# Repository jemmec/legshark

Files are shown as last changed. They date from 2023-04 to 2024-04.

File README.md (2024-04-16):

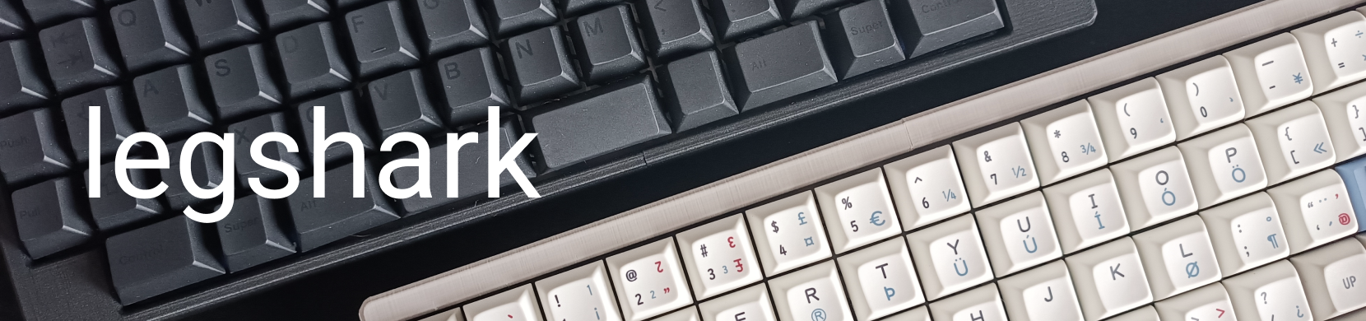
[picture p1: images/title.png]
title


# legshark

An open source 60% (15 by 5) ortholinear keyboard designed with both flexability and familiarity in mind.

- Highly customizable 60% ortho layout
- "Plateless" o-ring mounting
- 3D printable case
- [UDB](https://github.com/Unified-Daughterboard/) Support

### Layout

The PCB supports many different layout options for the bottom row, embracing `1u` keys but also with some left and right `1.5u` modifier options.

The board also supports use of `2u` keys in the usual `TAB`, `LSHIFT`, `DELETE`, and `ENTER` locations to maintain familiarity and speed with these often used modifiers.

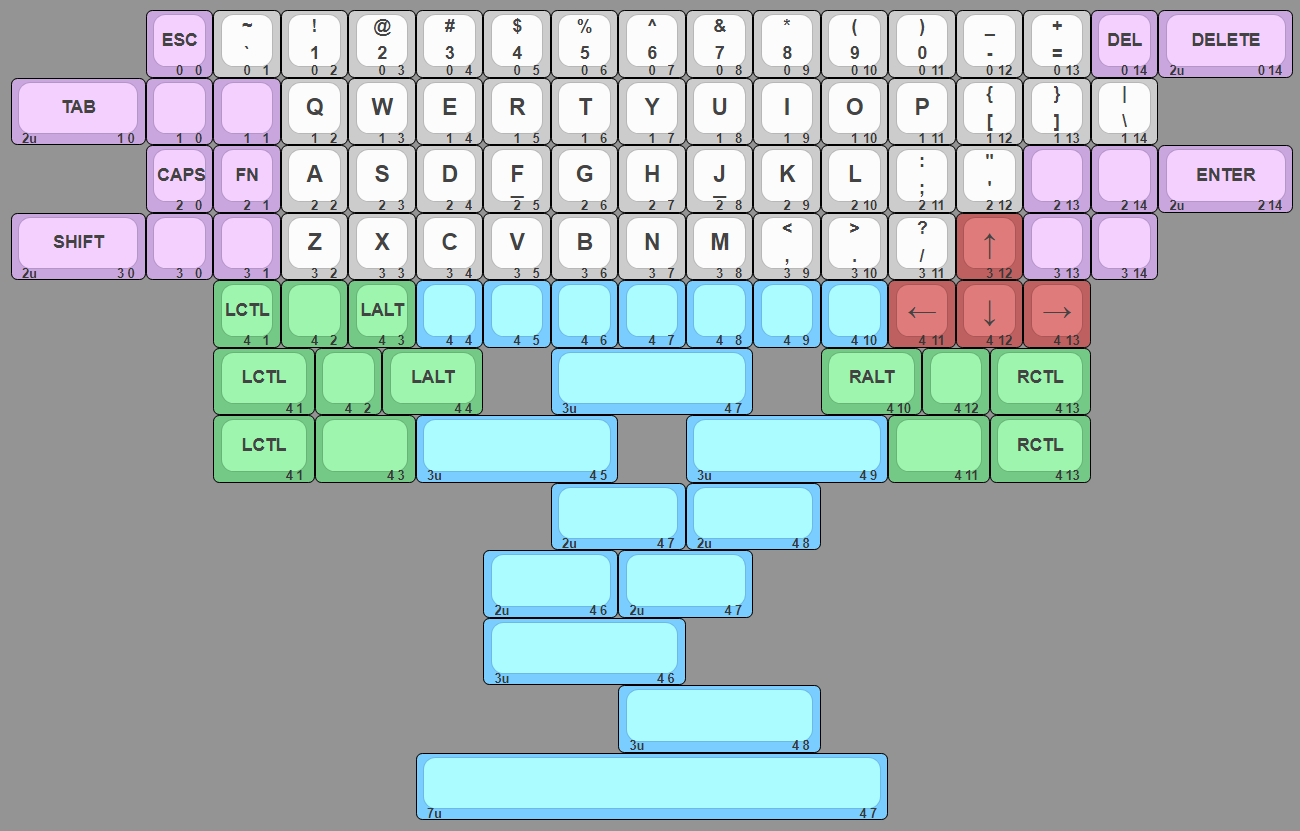
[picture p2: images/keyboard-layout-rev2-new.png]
keyboard-layout Rev2


### PCB

> NOTE: It is recommended to use screw-in stabilizers (yes they work with o-ring) due to clip-ins sometimes slipping between the three holes in the bottom row. I have slightly reduced the clip-in hole size which has mitigated the issue, but made them quite hard to push in.

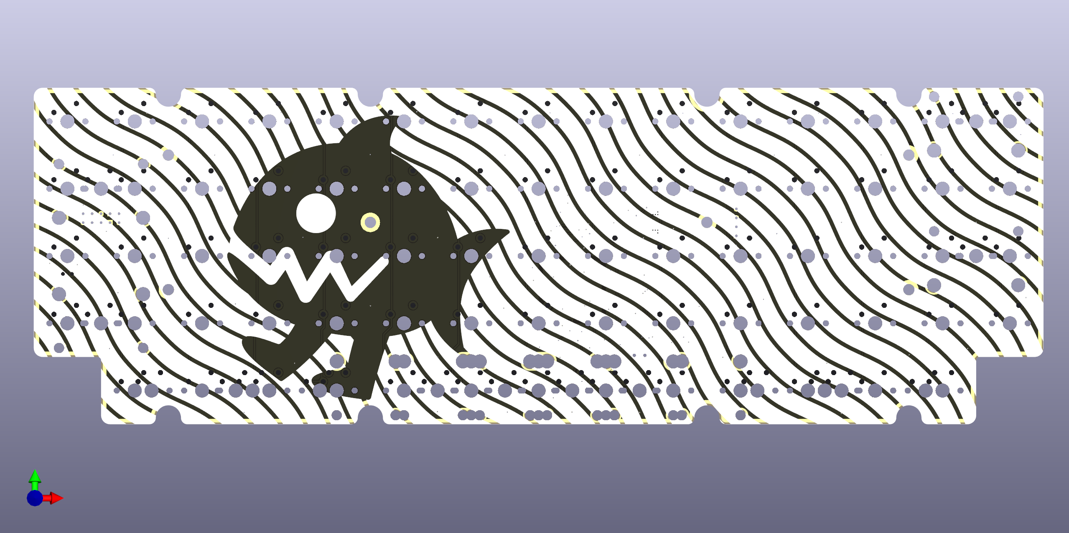
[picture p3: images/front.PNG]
front

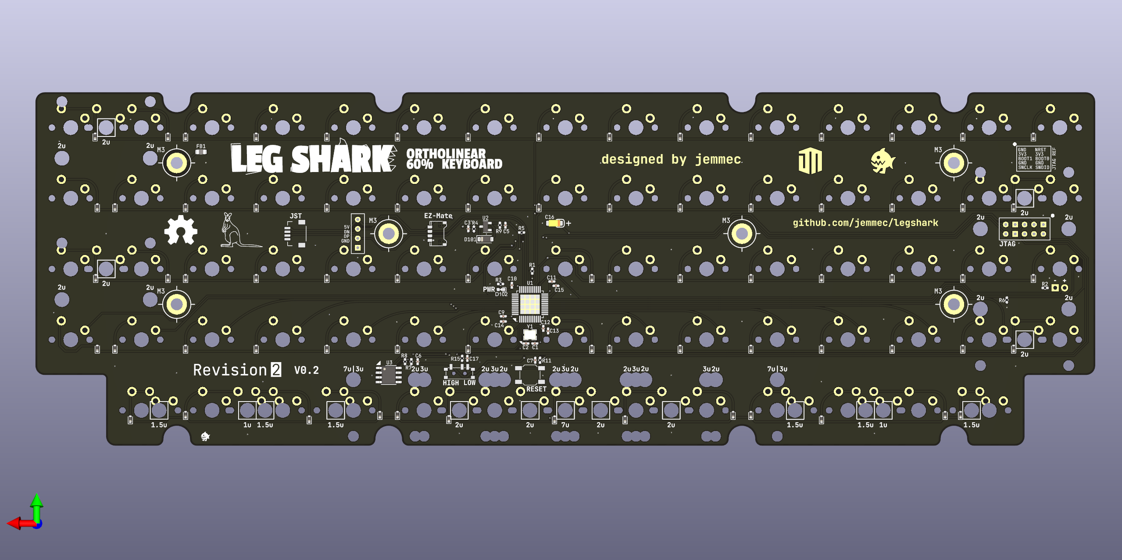
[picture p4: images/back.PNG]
back

>_These images may not be up-to-date._

Supports the [Unified Daughterboard](https://github.com/Unified-Daughterboard/).

### Mounting Styles

Supports a unique "plateless" o-ring mounting style. The PCB also has through-holes for plate mounting should that be preferred.

#### "Plateless" o-ring plate

The "plateless" o-ring mounting style lets you enjoy the unique characteristics and sound of a platless + o-ring board with the added benefit of being able to remove/change the plate after soldering in the switches.

The printable plate files can be found in `./stls`. There are two files, one for `1.5u` spaced switches (pictured) and one for the `1u` spaced switches. Only the left side plate is supplied, you will need to vertically mirror the file in your slicer to print the right side. The optimal printing orientation is upside-down.

A standard 60% o-ring (OD 180-190mm) with a diameter of 2.5-3.5mm will work. 

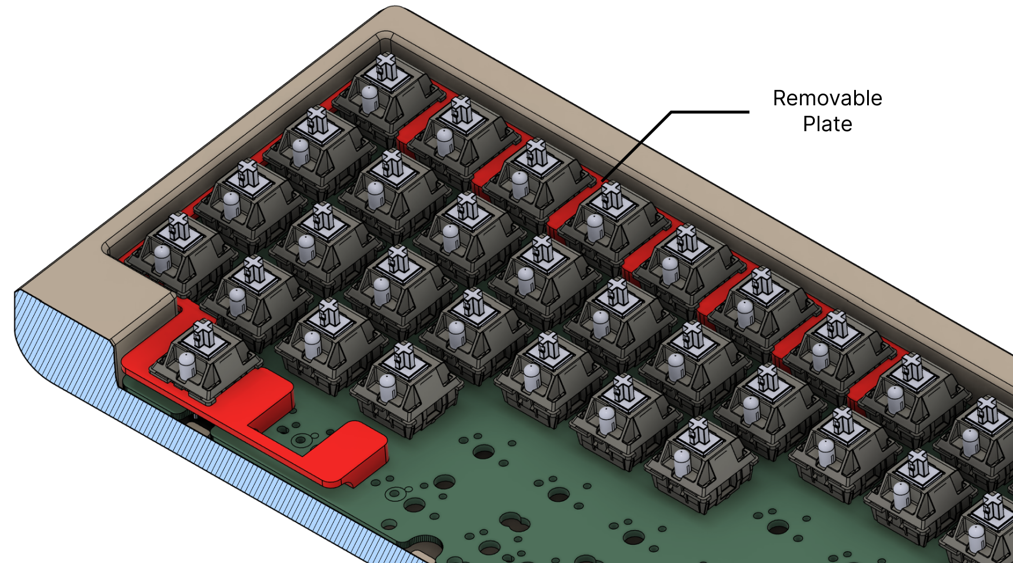
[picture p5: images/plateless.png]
plateless


>NOTE: If you intend to use a layout with the `2u` SHIFT or DELETE keys these plates may need modified in order to fit the stabs.

### Case

A 3D printable case designed around the "plateless" o-ring mounting system. It's a unibody design with a daughterboard cutout and recessed holes for 12mm rubber feet. The daughterboard is screwed into M2 threaded inserts.

Files for printing the case can be found in `./stls`. The print has been split into two parts, since it is too large for standard-sized printer volumes. The two halves are designed to be glued together using key and slot guides for alignment and added strength. The optimal printing orientation is vertically with the case-sides facing down.

>NOTE: I recommend using superglue to bond the two halves together.
>1) Glue all three keys into the slots of one of the halves. 
>2) Add glue along the mating surface and in the slots of the other half. 
>3) Carefully slide the two halves together using the keys and slots a guide. 
>4) Clamp the halves together and let the glue dry for 10-20 minutes.

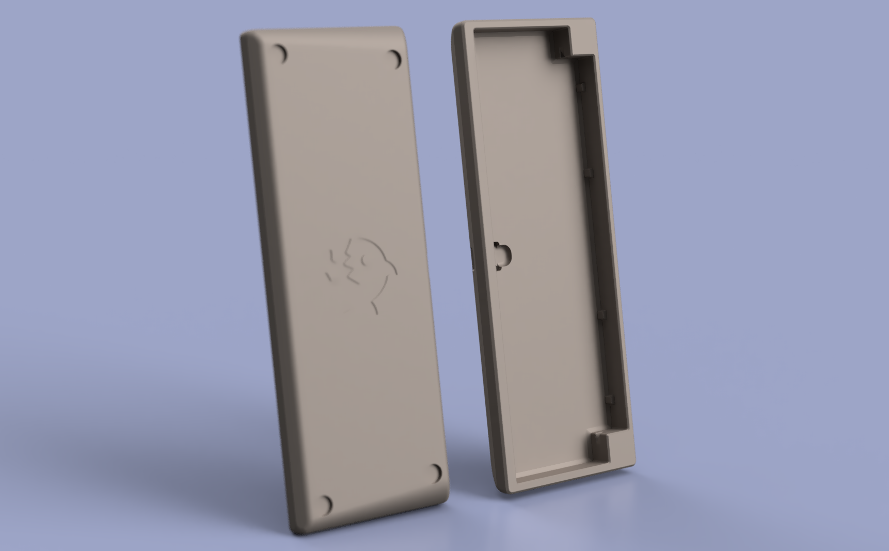
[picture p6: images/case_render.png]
case


### QMK

There is only one keymap avaliable for the keyboard currently. This keyboard has not been merged into the qmk repo yet. The firmware will need to be compiled and uploaded locally using [QMK](https://qmk.fm/). 

Copy `./qmk/keyboards` into your `/qmk_firmware` folder then run the following command to compile the firmware:
```
qmk compile -kb legshark/rev2 -km default
```

>NOTE: You will need to modify the keymaps to support different layouts!

### Keyboard Layout Editor:

```
[{x:2,c:"#c9a6de",t:"#383838",st:"KS-3-Tea",a:3,f:4},"ESC\n\n\n\n\n0\n\n\n\n\n\n0",{c:"#cccccc",a:1},"~\n`\n\n\n\n1\n\n\n\n\n\n0","!\n1\n\n\n\n2\n\n\n\n\n\n0","@\n2\n\n\n\n3\n\n\n\n\n\n0","#\n3\n\n\n\n4\n\n\n\n\n\n0","$\n4\n\n\n\n5\n\n\n\n\n\n0","%\n5\n\n\n\n6\n\n\n\n\n\n0","^\n6\n\n\n\n7\n\n\n\n\n\n0","&\n7\n\n\n\n8\n\n\n\n\n\n0","*\n8\n\n\n\n9\n\n\n\n\n\n0","(\n9\n\n\n\n10\n\n\n\n\n\n0",")\n0\n\n\n\n11\n\n\n\n\n\n0","_\n-\n\n\n\n12\n\n\n\n\n\n0","+\n=\n\n\n\n13\n\n\n\n\n\n0",{c:"#c9a6de",a:3},"DEL\n\n\n\n\n14\n\n\n\n\n\n0",{w:2},"DELETE\n\n\n\n2u\n0 14"],
[{w:2},"TAB\n\n\n\n2u\n1 0","\n\n\n\n\n0\n\n\n\n\n\n1","\n\n\n\n\n1\n\n\n\n\n\n1",{c:"#cccccc",f:6},"Q\n\n\n\n\n2\n\n\n\n\n\n1","W\n\n\n\n\n3\n\n\n\n\n\n1","E\n\n\n\n\n4\n\n\n\n\n\n1","R\n\n\n\n\n5\n\n\n\n\n\n1","T\n\n\n\n\n6\n\n\n\n\n\n1","Y\n\n\n\n\n7\n\n\n\n\n\n1","U\n\n\n\n\n8\n\n\n\n\n\n1","I\n\n\n\n\n9\n\n\n\n\n\n1","O\n\n\n\n\n10\n\n\n\n\n\n1","P\n\n\n\n\n11\n\n\n\n\n\n1",{a:1,f:4},"{\n[\n\n\n\n12\n\n\n\n\n\n1","}\n]\n\n\n\n13\n\n\n\n\n\n1","|\n\\\n\n\n\n14\n\n\n\n\n\n1"],
[{x:2,c:"#c9a6de",a:3},"CAPS\n\n\n\n\n0\n\n\n\n\n\n2","FN\n\n\n\n\n1\n\n\n\n\n\n2",{c:"#cccccc",f:6},"A\n\n\n\n\n2\n\n\n\n\n\n2","S\n\n\n\n\n3\n\n\n\n\n\n2","D\n\n\n\n\n4\n\n\n\n\n\n2",{a:1},"\n_\n\n\n\n5\nF\n\n\n\n\n2",{a:3},"G\n\n\n\n\n6\n\n\n\n\n\n2","H\n\n\n\n\n7\n\n\n\n\n\n2",{a:1},"\n_\n\n\n\n8\nJ\n\n\n\n\n2",{a:3},"K\n\n\n\n\n9\n\n\n\n\n\n2","L\n\n\n\n\n10\n\n\n\n\n\n2",{a:1,f:4},":\n;\n\n\n\n11\n\n\n\n\n\n2","\"\n'\n\n\n\n12\n\n\n\n\n\n2",{c:"#c9a6de",a:3},"\n\n\n\n\n13\n\n\n\n\n\n2","\n\n\n\n\n14\n\n\n\n\n\n2",{w:2},"ENTER\n\n\n\n2u\n2 14"],
[{w:2},"SHIFT\n\n\n\n2u\n3 0","\n\n\n\n\n0\n\n\n\n\n\n3","\n\n\n\n\n1\n\n\n\n\n\n3",{c:"#cccccc",f:6},"Z\n\n\n\n\n2\n\n\n\n\n\n3","X\n\n\n\n\n3\n\n\n\n\n\n3","C\n\n\n\n\n4\n\n\n\n\n\n3","V\n\n\n\n\n5\n\n\n\n\n\n3","B\n\n\n\n\n6\n\n\n\n\n\n3","N\n\n\n\n\n7\n\n\n\n\n\n3","M\n\n\n\n\n8\n\n\n\n\n\n3",{a:1,f:4},"<\n,\n\n\n\n9\n\n\n\n\n\n3",">\n.\n\n\n\n10\n\n\n\n\n\n3","?\n/\n\n\n\n11\n\n\n\n\n\n3",{c:"#bf6060",a:3,f:9},"↑\n\n\n\n\n12\n\n\n\n\n\n3",{c:"#c9a6de",f:4},"\n\n\n\n\n13\n\n\n\n\n\n3","\n\n\n\n\n14\n\n\n\n\n\n3"],
[{x:3,c:"#73c985"},"LCTL\n\n\n\n\n1\n\n\n\n\n\n4","\n\n\n\n\n2\n\n\n\n\n\n4","LALT\n\n\n\n\n3\n\n\n\n\n\n4",{c:"#7acdff",sm:"alps"},"\n\n\n\n\n4\n\n\n\n\n\n4","\n\n\n\n\n5\n\n\n\n\n\n4","\n\n\n\n\n6\n\n\n\n\n\n4","\n\n\n\n\n7\n\n\n\n\n\n4","\n\n\n\n\n8\n\n\n\n\n\n4","\n\n\n\n\n9\n\n\n\n\n\n4","\n\n\n\n\n10\n\n\n\n\n\n4",{c:"#bf6060",f:9},"←\n\n\n\n\n11\n\n\n\n\n\n4","↓\n\n\n\n\n12\n\n\n\n\n\n4","→\n\n\n\n\n13\n\n\n\n\n\n4"],
[{x:3,c:"#73c985",f:4,w:1.5},"LCTL\n\n\n\n\n4 1","\n\n\n\n\n2\n\n\n\n\n\n4",{w:1.5},"LALT\n\n\n\n\n4 4",{x:1,c:"#7acdff",w:3},"\n\n\n\n3u\n4 7",{x:1,c:"#73c985",w:1.5},"RALT\n\n\n\n\n4 10","\n\n\n\n\n4 12",{w:1.5},"RCTL\n\n\n\n\n4 13"],
[{x:3,w:1.5},"LCTL\n\n\n\n\n4 1",{w:1.5},"\n\n\n\n\n4 3",{c:"#7acdff",w:3},"\n\n\n\n3u\n4 5",{x:1,w:3},"\n\n\n\n3u\n4 9",{c:"#73c985",w:1.5},"\n\n\n\n\n4 11",{w:1.5},"RCTL\n\n\n\n\n4 13"],
[{x:8,c:"#7acdff",w:2},"\n\n\n\n2u\n4 7",{w:2},"\n\n\n\n2u\n4 8"],
[{x:7,w:2},"\n\n\n\n2u\n4 6",{w:2},"\n\n\n\n2u\n4 7"],
[{x:7,w:3},"\n\n\n\n3u\n4 6"],
[{x:9,w:3},"\n\n\n\n3u\n4 8"],
[{x:6,w:7},"\n\n\n\n7u\n4 7"]
```
# Liability

This open source hardware is provided as is and can not be held accountable for any damages and/or liabilities caused as a result of whatever you intend to use it for.

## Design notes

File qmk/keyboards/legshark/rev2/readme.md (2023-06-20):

# legshark65

legshark65

*A short description of the keyboard/project*

* Keyboard Maintainer: [jemmec](https://github.com/jemmec)
* Hardware Supported: *The PCBs, controllers supported*
* Hardware Availability: *Links to where you can find this hardware*

Make example for this keyboard (after setting up your build environment):

    make legshark65:default

Flashing example for this keyboard:

    make legshark65:default:flash

See the [build environment setup](https://docs.qmk.fm/#/getting_started_build_tools) and the [make instructions](https://docs.qmk.fm/#/getting_started_make_guide) for more information. Brand new to QMK? Start with our [Complete Newbs Guide](https://docs.qmk.fm/#/newbs).

## Bootloader

Enter the bootloader in 3 ways:

* **Bootmagic reset**: Hold down the key at (0,0) in the matrix (usually the top left key or Escape) and plug in the keyboard
* **Physical reset button**: Briefly press the button on the back of the PCB - some may have pads you must short instead
* **Keycode in layout**: Press the key mapped to `QK_BOOT` if it is available

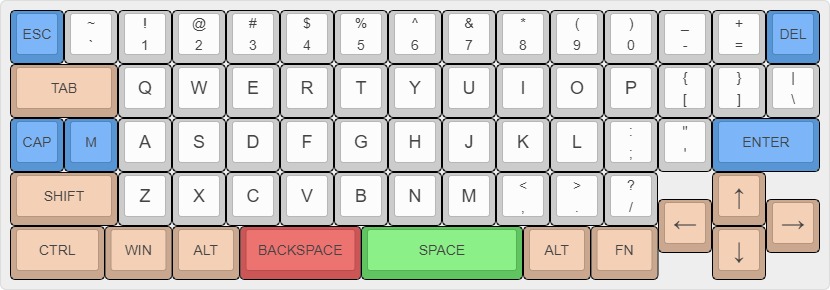
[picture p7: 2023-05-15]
images/keyboard-layout-v2.1.jpg

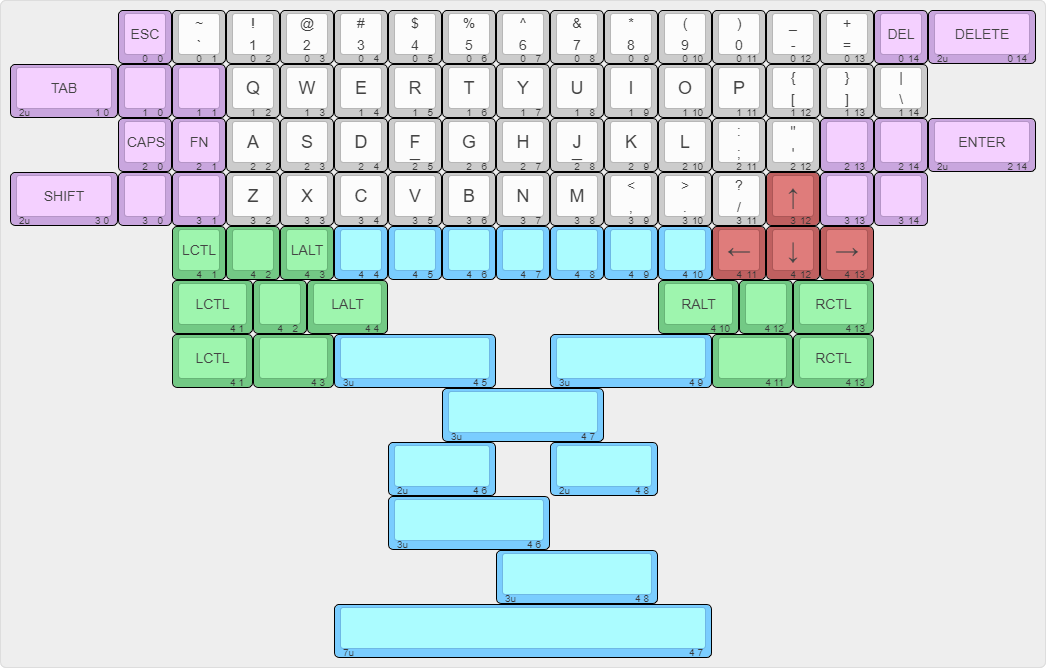
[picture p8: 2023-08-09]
images/keyboard-layout_rev2.png

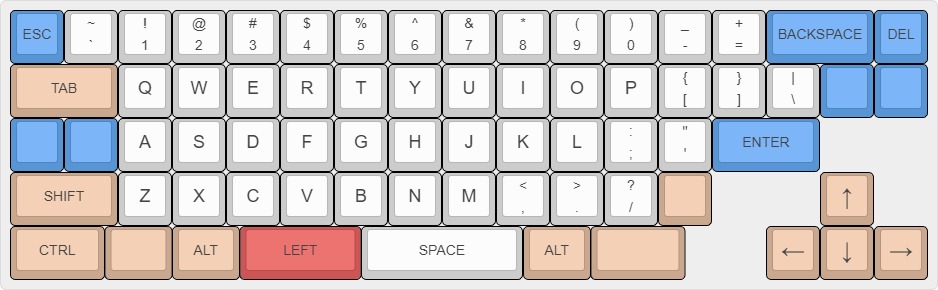
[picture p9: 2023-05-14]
images/keyboard-layout-v2.jpg

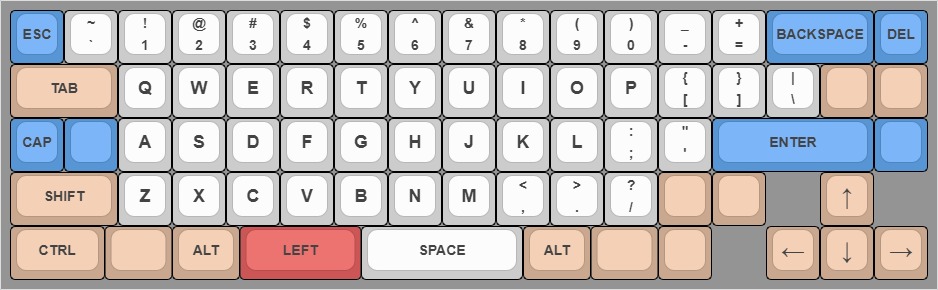
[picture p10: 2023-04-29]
images/keyboard-layout-v1.jpg

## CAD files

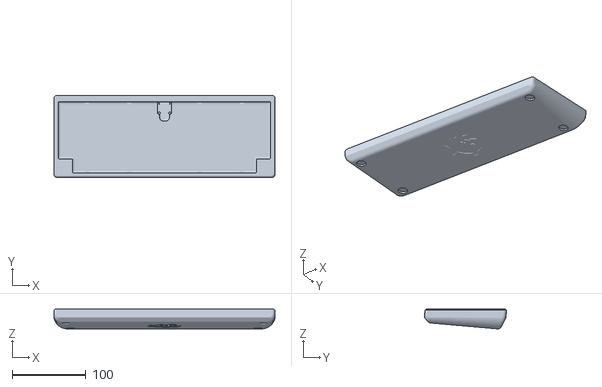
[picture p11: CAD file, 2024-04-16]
stls/case-body-whole.stl
298.8 x 111.1 x 26.7

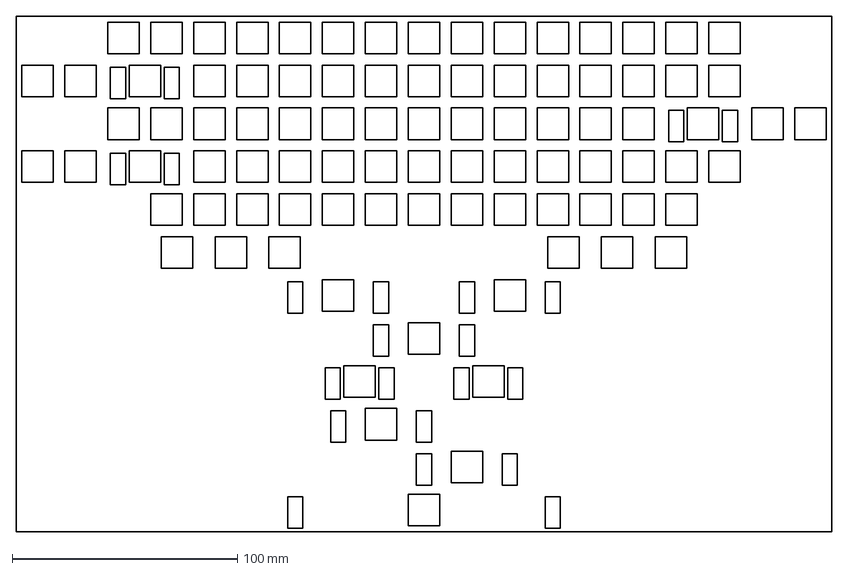
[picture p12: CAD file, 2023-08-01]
plate/Rev2/plate-2023-08-01T08_43_06.286Z.dxf
361.9 x 228.6 mm

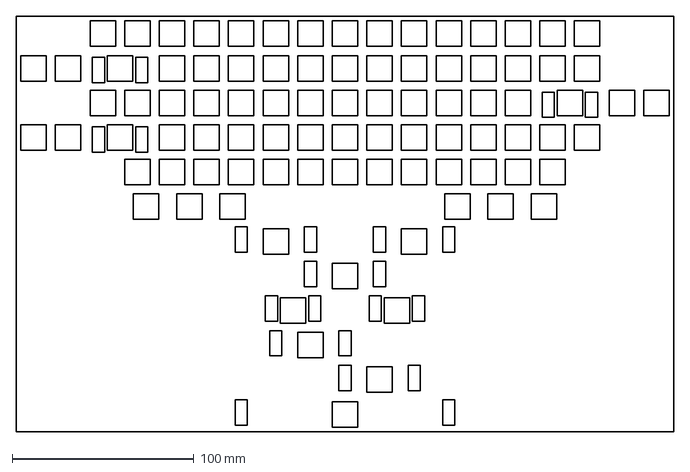
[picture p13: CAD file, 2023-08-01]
plates/rev2/legshark65_rev2_plate.dxf
361.9 x 228.6 mm

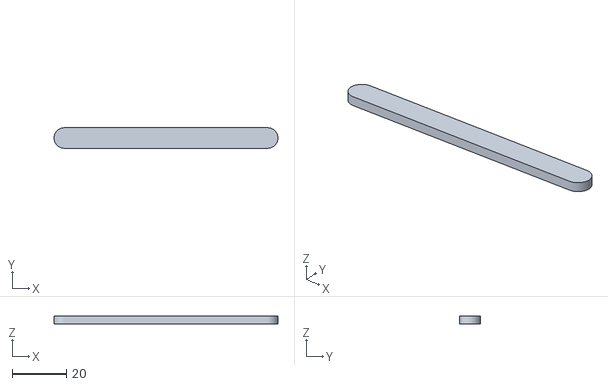
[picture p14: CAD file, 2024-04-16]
stls/case-key-small.stl
82.6 x 7.60 x 2.80

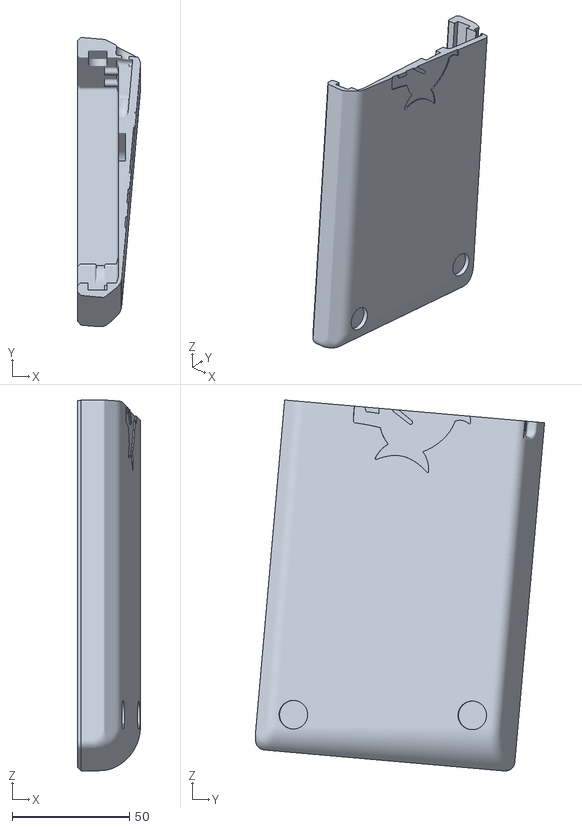
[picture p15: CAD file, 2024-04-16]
stls/case-body-left.stl
26.7 x 123.1 x 158.0

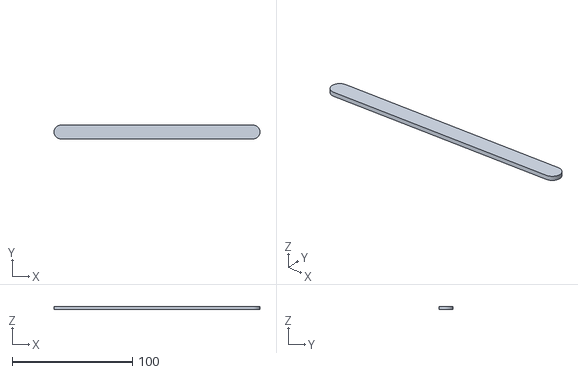
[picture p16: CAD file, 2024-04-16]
stls/case-key-large.stl
171.6 x 11.6 x 2.80

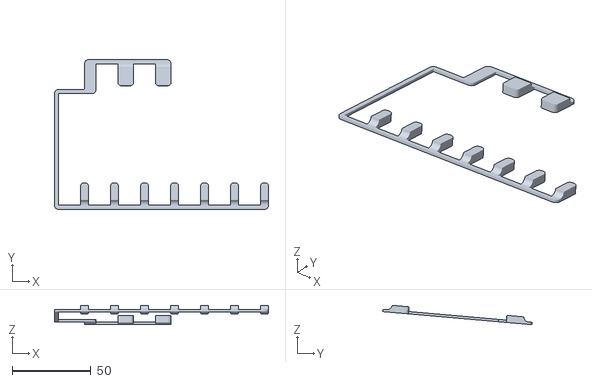
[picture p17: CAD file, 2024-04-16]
stls/plate-1.5u-left.stl
135.9 x 95.0 x 12.3

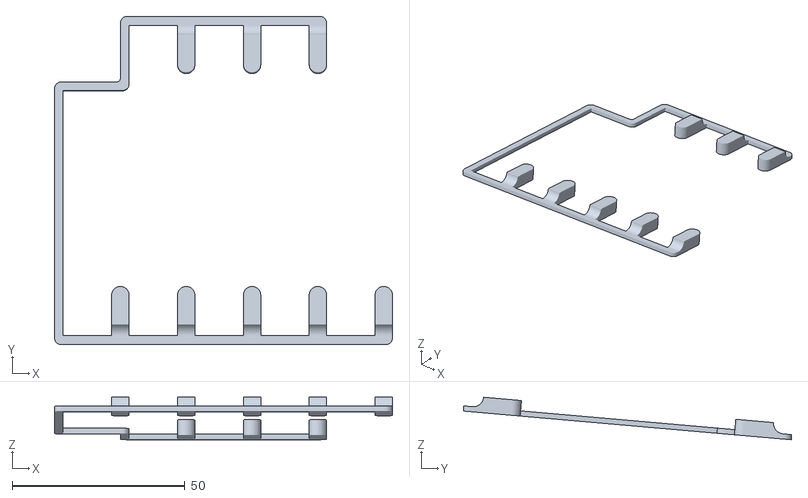
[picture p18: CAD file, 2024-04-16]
stls/plate-1u-left.stl
97.8 x 95.0 x 12.3

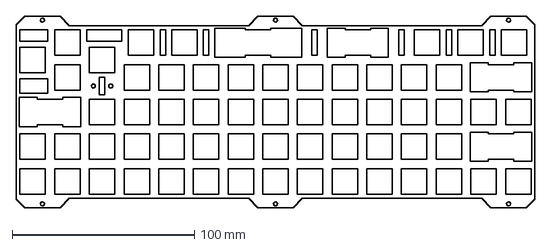
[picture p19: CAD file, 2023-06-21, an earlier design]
plates/rev1/legshark65_plate_0.50tol.dxf
285.0 x 105.0 mm

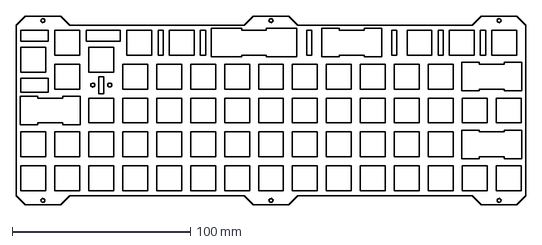
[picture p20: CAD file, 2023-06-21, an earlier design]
plates/rev1/legshark65_plate_0.15tol.dxf
285.7 x 105.7 mm

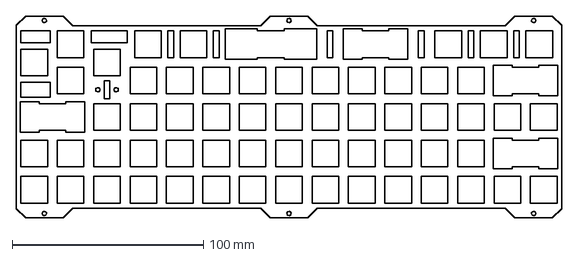
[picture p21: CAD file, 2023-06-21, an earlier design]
plates/rev1/legshark65_plate_0.25tol.dxf
285.5 x 105.5 mm

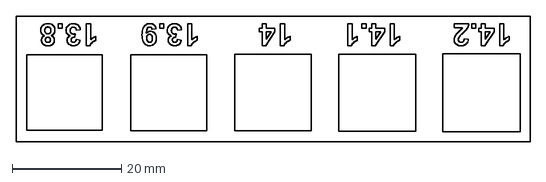
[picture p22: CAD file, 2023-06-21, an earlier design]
plates/rev1/legshark65_switch_tolerance_test.dxf
94.0 x 23.0 mm

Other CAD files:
stls/case-body-right.stl

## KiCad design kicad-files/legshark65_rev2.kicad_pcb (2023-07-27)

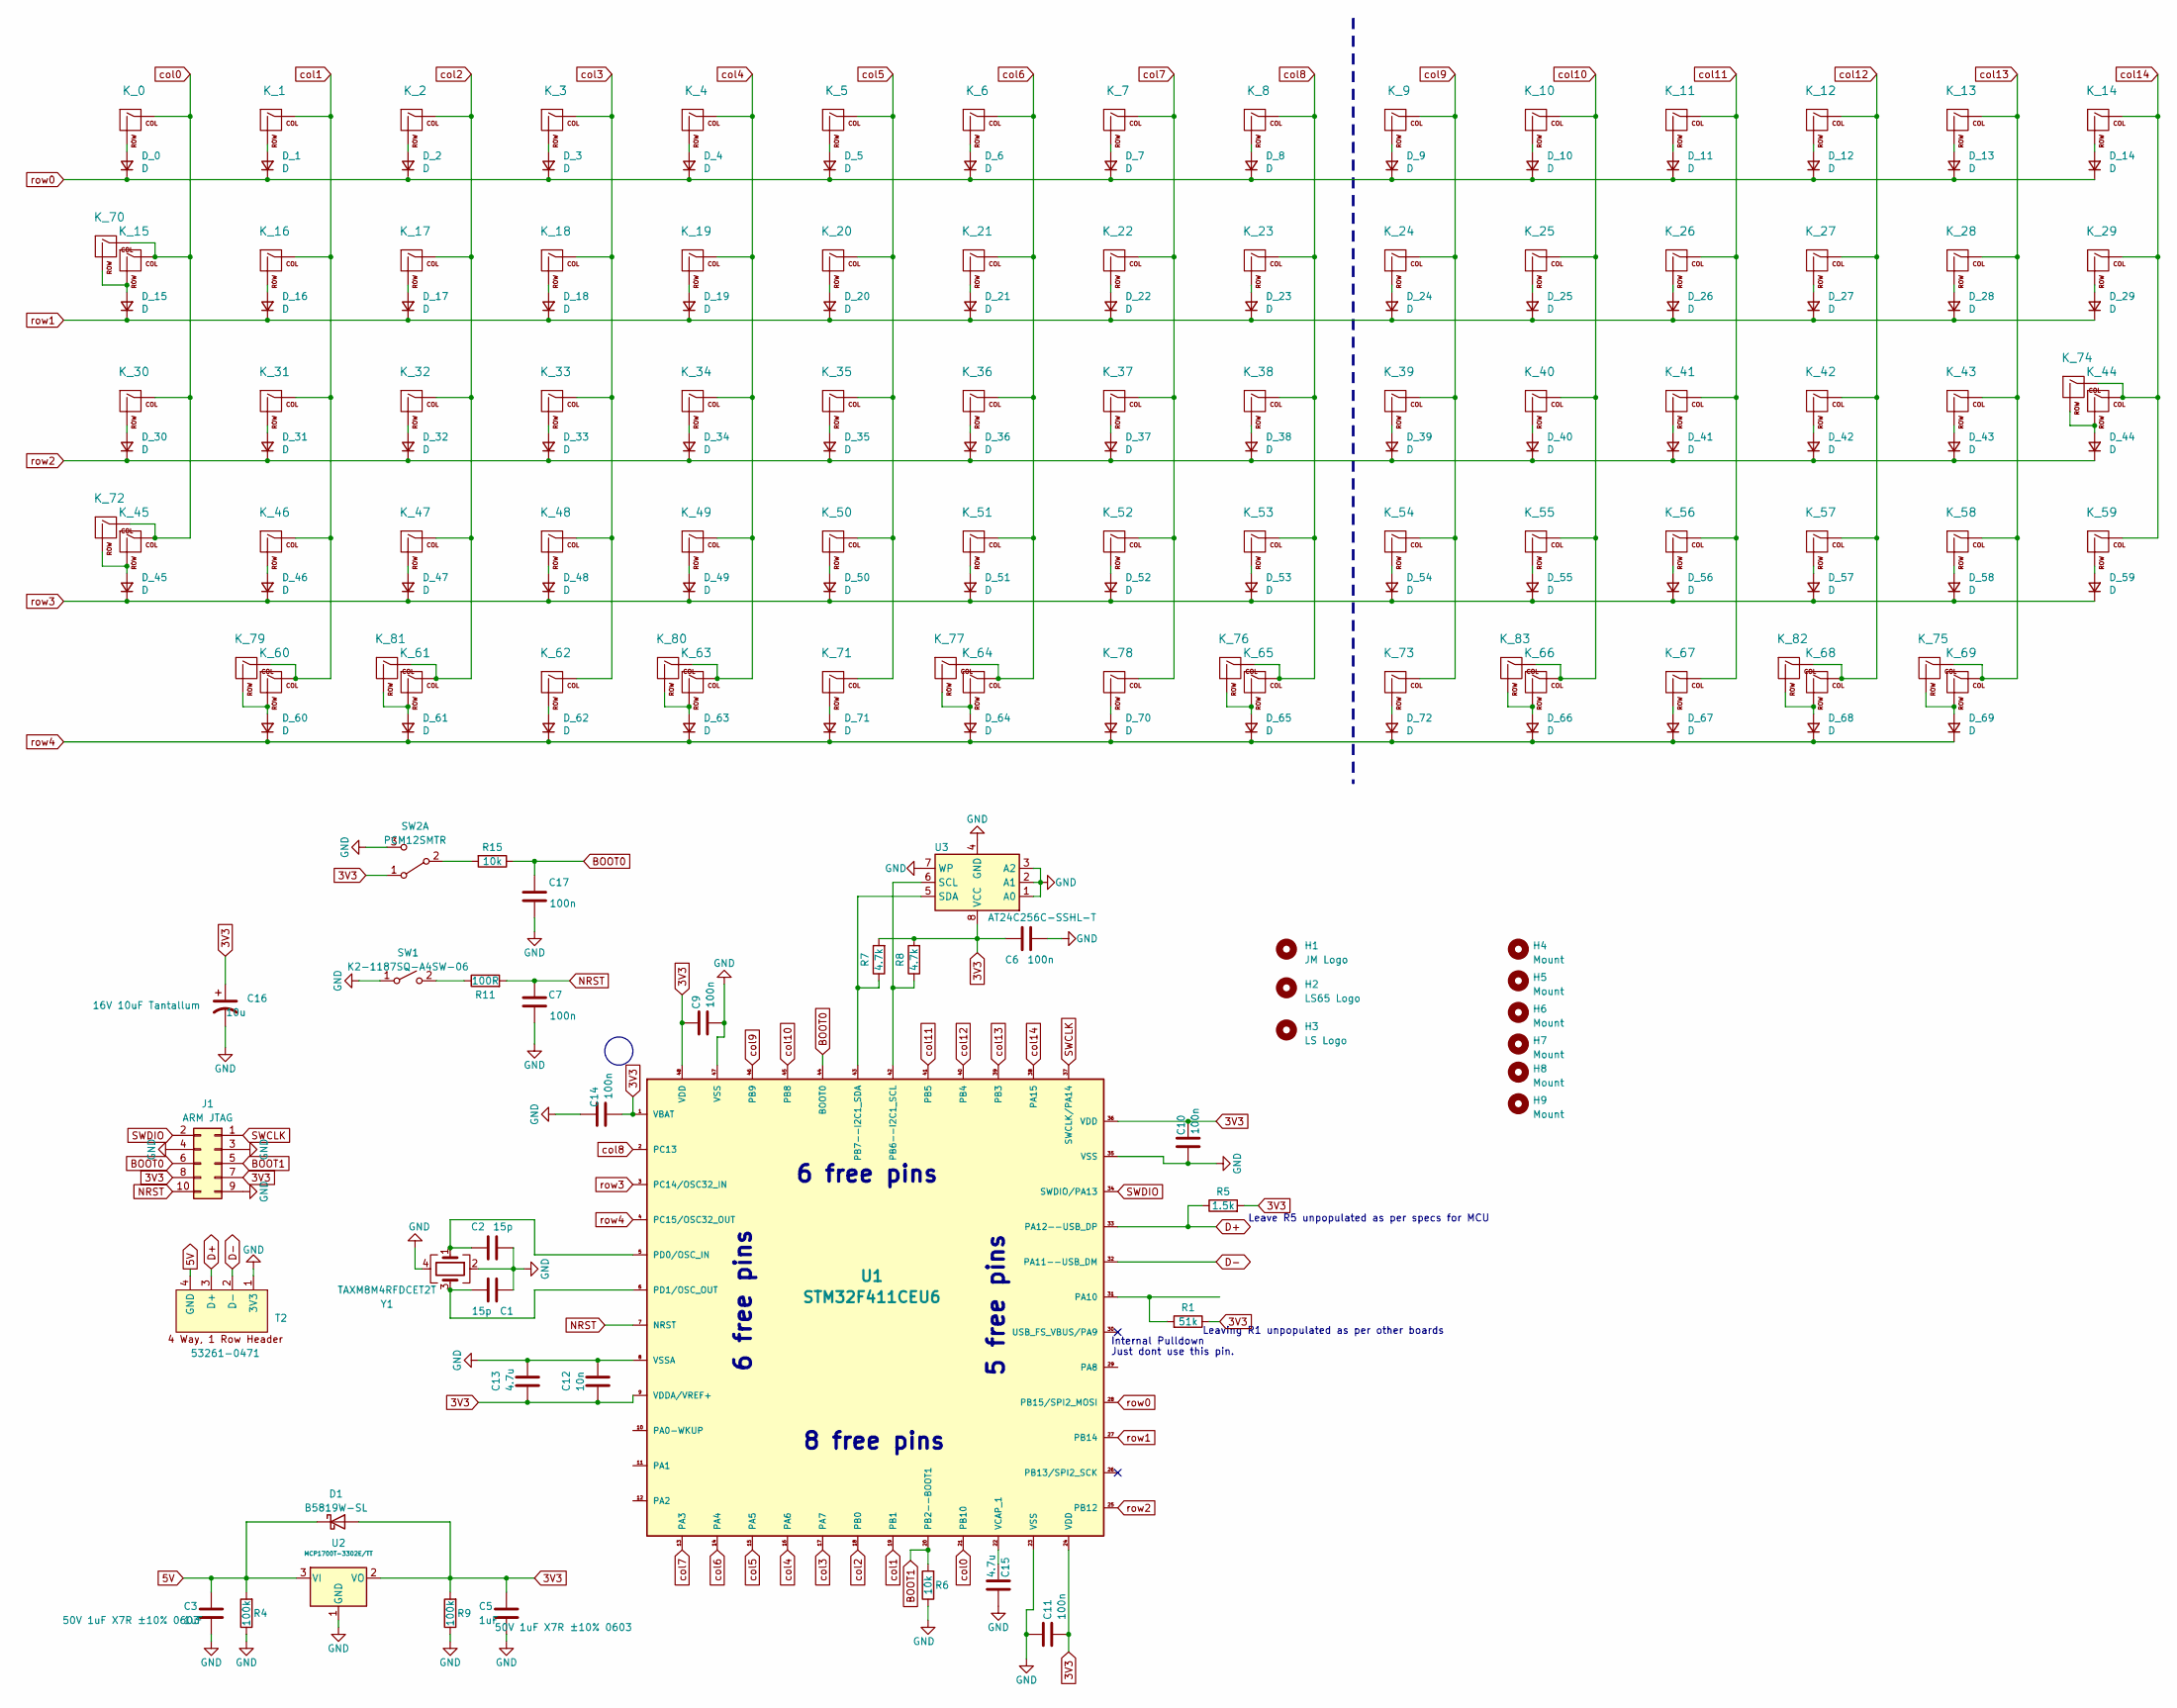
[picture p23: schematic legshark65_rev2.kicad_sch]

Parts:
C1, C2: 15p; C_0402_1005Metric_Pad0.74x0.62mm_HandSolder; Manufacturer Part Number CC0603JRNPO9BN150; LCSC Part C107037
C3, C5: 1uF; C_0402_1005Metric_Pad0.74x0.62mm_HandSolder; Manufacturer Part Number 0603B105K500NT
C6, C7, C9, C10, C11, C14, C17: 100n; C_0402_1005Metric_Pad0.74x0.62mm_HandSolder; Manufacturer Part Number CL10B104KB8NNNC; LCSC Part C1591
C12: 10n; C_0402_1005Metric_Pad0.74x0.62mm_HandSolder; Manufacturer Part Number CL10B103KB8NNNC; LCSC Part C1589
C13, C15: 4.7u; C_0402_1005Metric_Pad0.74x0.62mm_HandSolder; Manufacturer Part Number 0603X475M100NT; LCSC Part C108342
C16: 10u; CP_EIA-3216-10_Kemet-I_Pad1.58x1.35mm_HandSolder; Manufacturer Part Number TAJA106K016RNJ; LCSC Part C7171
D1: B5819W-SL; D_SOD-123
D_0, D_1, D_2, D_3, D_4, D_5, D_6, D_7, D_8, D_9, D_10, D_11, D_12, D_13, D_14, D_15, D_16, D_17, D_18, D_19, D_20, D_21, D_22, D_23, D_24, D_25, D_26, D_27, D_28, D_29, D_30, D_31, D_32, D_33, D_34, D_35, D_36, D_37, D_38, D_39, D_40, D_41, D_42, D_43, D_44, D_45, D_46, D_47, D_48, D_49, D_50, D_51, D_52, D_53, D_54, D_55, D_56, D_57, D_58, D_59, D_60, D_61, D_62, D_63, D_64, D_65, D_66, D_67, D_68, D_69, D_70, D_71, D_72: D; D_SOD-523
H1: JM Logo; jm_logo
H2: LS65 Logo; ls65_logo
H3: LS Logo; Legshark_Mask
H4, H5, H6, H7, H8, H9: Mount; MountingHole_3.2mm_M3_ISO14580
J1: ARM JTAG; PinHeader_2x5_P2.54mm_Vertical
K_0, K_1, K_2, K_3, K_4, K_5, K_6, K_7, K_8, K_9, K_10, K_11, K_12, K_13, K_14, K_15, K_16, K_17, K_18, K_19, K_20, K_21, K_22, K_23, K_24, K_25, K_26, K_27, K_28, K_29, K_30, K_31, K_32, K_33, K_34, K_35, K_36, K_37, K_38, K_39, K_40, K_41, K_42, K_43, K_44, K_45, K_46, K_47, K_48, K_49, K_50, K_51, K_52, K_53, K_54, K_55, K_56, K_57, K_58, K_59, K_60, K_61, K_62, K_63, K_66, K_67, K_68, K_69, K_71, K_73, K_81, K_82: KEYSW; MXOnly-1U-NoLED
K_64, K_76: KEYSW; MXOnly-2U-ReversedStabilizers-NoLED
K_65, K_77: KEYSW; MXOnly-3U-ReversedStabilizers-NoLED
K_70, K_72, K_74: KEYSW; MXOnly-2U-NoLED
K_75, K_79, K_80, K_83: KEYSW; MXOnly-1.5U-NoLED
K_78: KEYSW; Legshark_MXOnly-7U-3U-ReversedStabilizers-NoLED
R1: 51k; R_0402_1005Metric_Pad0.72x0.64mm_HandSolder
R4, R9: 100k; R_0402_1005Metric_Pad0.72x0.64mm_HandSolder
R5: 1.5k; R_0402_1005Metric_Pad0.72x0.64mm_HandSolder
R6, R15: 10k; R_0402_1005Metric_Pad0.72x0.64mm_HandSolder; Manufacturer Part Number 0603WAF1002T5E; LCSC Part C25804
R7, R8: 4.7k; R_0402_1005Metric_Pad0.72x0.64mm_HandSolder; Manufacturer Part Number 0603WAF4701T5E; LCSC Part C23162
R11: 100R; R_0402_1005Metric_Pad0.72x0.64mm_HandSolder; Manufacturer Part Number 0603WAF1000T5E; LCSC Part C22775
SW1: K2-1187SQ-A4SW-06; Manufacturer Part Number K2-1187SQ-A4SW-06; LCSC Part C92584
SW2: PCM12SMTR; Surface Mount Slide Switch SPDT; Manufacturer Part Number PCM12SMTR; LCSC Part C221841
T2: 53261-0471; Molex, PicoBlade, 53261, 4 Way, 1 Row, Right Angle PCB Head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
U1: STM32F411CEU6; STM_UFQFPN-48_LQFP-48-1EP_7x7mm_P0.5mm_HandSoldering; Manufacturer Part Number STM32F411; LCSC Part C60420
U2: MCP1700T-3302E/TT; SOT-23; Manufacturer Part Number MCP1700T-3302E/TT
U3: AT24C256C-SSHL-T; SOIC-8; Manufacturer Part Number AT24C256C-SSHL-T; LCSC Part C6482
Y1: TAXM8M4RFDCET2T; Crystal_SMD_3225-4Pin_3.2x2.5mm; Manufacturer Part Number TAXM8M4RFDCET2T; LCSC Part C403948

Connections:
3V3: C5.1, C6.1, C9.2, C10.2, C11.2, C12.2, C13.2, C14.1, C16.1, D1.2 (A), J1.7, J1.8, R1.1, R5.2, R7.2, R8.2, R9.2, SW2.1 (A), U1.1 (VBAT), U1.9 (VDDA/VREF+), U1.24 (VDD), U1.36 (VDD), U1.48 (VDD), U2.2 (VO), U3.8 (VCC)
5V: C3.1, D1.1 (K), R4.2, T2.4 (GND), U2.3 (VI)
BOOT0: C17.2, J1.6, R15.1, U1.44 (BOOT0)
BOOT1: J1.5, R6.2, U1.20 (PB2--BOOT1)
D+: R5.1, T2.3 (D+), U1.33 (PA12--USB_DP)
D-: T2.2 (D-), U1.32 (PA11--USB_DM)
GND: C1.1, C2.2, C3.2, C5.2, C6.2, C7.1, C9.1, C10.1, C11.1, C12.1, C13.1, C14.2, C15.2, C16.2, C17.1, J1.3, J1.4, J1.9, R4.1, R6.1, R9.1, SW1.1 (A), SW2.3 (C), T2.1 (3V3), U1.8 (VSSA), U1.23 (VSS), U1.35 (VSS), U1.47 (VSS), U2.1 (GND), U3.1 (A0), U3.2 (A1), U3.3 (A2), U3.4 (GND), U3.7 (WP), Y1.2, Y1.4
NRST: C7.2, J1.10, R11.2, U1.7 (NRST)
unnamed: D_0.2 (A), K_0.2 (ROW)
unnamed: D_1.2 (A), K_1.2 (ROW)
unnamed: D_2.2 (A), K_2.2 (ROW)
unnamed: D_3.2 (A), K_3.2 (ROW)
unnamed: D_4.2 (A), K_4.2 (ROW)
unnamed: D_5.2 (A), K_5.2 (ROW)
unnamed: D_6.2 (A), K_6.2 (ROW)
unnamed: D_7.2 (A), K_7.2 (ROW)
unnamed: D_8.2 (A), K_8.2 (ROW)
unnamed: D_9.2 (A), K_9.2 (ROW)
unnamed: D_10.2 (A), K_10.2 (ROW)
unnamed: D_11.2 (A), K_11.2 (ROW)
unnamed: D_12.2 (A), K_12.2 (ROW)
unnamed: D_13.2 (A), K_13.2 (ROW)
unnamed: D_14.2 (A), K_14.2 (ROW)
unnamed: D_15.2 (A), K_15.2 (ROW), K_70.2 (ROW)
unnamed: D_16.2 (A), K_16.2 (ROW)
unnamed: D_17.2 (A), K_17.2 (ROW)
unnamed: D_18.2 (A), K_18.2 (ROW)
unnamed: D_19.2 (A), K_19.2 (ROW)
unnamed: D_20.2 (A), K_20.2 (ROW)
unnamed: D_21.2 (A), K_21.2 (ROW)
unnamed: D_22.2 (A), K_22.2 (ROW)
unnamed: D_23.2 (A), K_23.2 (ROW)
unnamed: D_24.2 (A), K_24.2 (ROW)
unnamed: D_25.2 (A), K_25.2 (ROW)
unnamed: D_26.2 (A), K_26.2 (ROW)
unnamed: D_27.2 (A), K_27.2 (ROW)
unnamed: D_28.2 (A), K_28.2 (ROW)
unnamed: D_29.2 (A), K_29.2 (ROW)
unnamed: D_30.2 (A), K_30.2 (ROW)
unnamed: D_31.2 (A), K_31.2 (ROW)
unnamed: D_32.2 (A), K_32.2 (ROW)
unnamed: D_33.2 (A), K_33.2 (ROW)
unnamed: D_34.2 (A), K_34.2 (ROW)
unnamed: D_35.2 (A), K_35.2 (ROW)
unnamed: D_36.2 (A), K_36.2 (ROW)
unnamed: D_37.2 (A), K_37.2 (ROW)
unnamed: D_38.2 (A), K_38.2 (ROW)
unnamed: D_39.2 (A), K_39.2 (ROW)
unnamed: D_40.2 (A), K_40.2 (ROW)
unnamed: D_41.2 (A), K_41.2 (ROW)
unnamed: D_42.2 (A), K_42.2 (ROW)
unnamed: D_43.2 (A), K_43.2 (ROW)
unnamed: D_44.2 (A), K_44.2 (ROW), K_74.2 (ROW)
unnamed: D_45.2 (A), K_45.2 (ROW), K_72.2 (ROW)
unnamed: D_46.2 (A), K_46.2 (ROW)
unnamed: D_47.2 (A), K_47.2 (ROW)
unnamed: D_48.2 (A), K_48.2 (ROW)
unnamed: D_49.2 (A), K_49.2 (ROW)
unnamed: D_50.2 (A), K_50.2 (ROW)
unnamed: D_51.2 (A), K_51.2 (ROW)
unnamed: D_52.2 (A), K_52.2 (ROW)
unnamed: D_53.2 (A), K_53.2 (ROW)
unnamed: D_54.2 (A), K_54.2 (ROW)
unnamed: D_55.2 (A), K_55.2 (ROW)
unnamed: D_56.2 (A), K_56.2 (ROW)
unnamed: D_57.2 (A), K_57.2 (ROW)
unnamed: D_58.2 (A), K_58.2 (ROW)
unnamed: D_59.2 (A), K_59.2 (ROW)
unnamed: D_60.2 (A), K_60.2 (ROW), K_79.2 (ROW)
unnamed: D_61.2 (A), K_61.2 (ROW), K_81.2 (ROW)
unnamed: D_62.2 (A), K_62.2 (ROW)
unnamed: D_63.2 (A), K_63.2 (ROW), K_80.2 (ROW)
unnamed: D_64.2 (A), K_64.2 (ROW), K_77.2 (ROW)
unnamed: D_65.2 (A), K_65.2 (ROW), K_76.2 (ROW)
unnamed: D_66.2 (A), K_66.2 (ROW), K_83.2 (ROW)
unnamed: D_67.2 (A), K_67.2 (ROW)
unnamed: D_68.2 (A), K_68.2 (ROW), K_82.2 (ROW)
unnamed: D_69.2 (A), K_69.2 (ROW), K_75.2 (ROW)
unnamed: D_70.2 (A), K_78.2 (ROW)
unnamed: D_71.2 (A), K_71.2 (ROW)
unnamed: D_72.2 (A), K_73.2 (ROW)
unnamed: R11.1, SW1.2 (B)
unnamed: R15.2, SW2.2 (B)
unnamed: R1.2, U1.31 (PA10)
unnamed: R8.1, U1.42 (PB6--I2C1_SCL), U3.6 (SCL)
unnamed: R7.1, U1.43 (PB7--I2C1_SDA), U3.5 (SDA)
unnamed: C2.1, U1.5 (PD0/OSC_IN), Y1.1
unnamed: C1.2, U1.6 (PD1/OSC_OUT), Y1.3
unnamed: C15.1, U1.22 (VCAP_1)
SWCLK: J1.1, U1.37 (SWCLK/PA14)
SWDIO: J1.2, U1.34 (SWDIO/PA13)
col0: K_0.1 (COL), K_15.1 (COL), K_30.1 (COL), K_45.1 (COL), K_70.1 (COL), K_72.1 (COL), U1.21 (PB10)
col1: K_1.1 (COL), K_16.1 (COL), K_31.1 (COL), K_46.1 (COL), K_60.1 (COL), K_79.1 (COL), U1.19 (PB1)
col2: K_2.1 (COL), K_17.1 (COL), K_32.1 (COL), K_47.1 (COL), K_61.1 (COL), K_81.1 (COL), U1.18 (PB0)
col3: K_3.1 (COL), K_18.1 (COL), K_33.1 (COL), K_48.1 (COL), K_62.1 (COL), U1.17 (PA7)
col4: K_4.1 (COL), K_19.1 (COL), K_34.1 (COL), K_49.1 (COL), K_63.1 (COL), K_80.1 (COL), U1.16 (PA6)
col5: K_5.1 (COL), K_20.1 (COL), K_35.1 (COL), K_50.1 (COL), K_71.1 (COL), U1.15 (PA5)
col6: K_6.1 (COL), K_21.1 (COL), K_36.1 (COL), K_51.1 (COL), K_64.1 (COL), K_77.1 (COL), U1.14 (PA4)
col7: K_7.1 (COL), K_22.1 (COL), K_37.1 (COL), K_52.1 (COL), K_78.1 (COL), U1.13 (PA3)
col8: K_8.1 (COL), K_23.1 (COL), K_38.1 (COL), K_53.1 (COL), K_65.1 (COL), K_76.1 (COL), U1.2 (PC13)
col9: K_9.1 (COL), K_24.1 (COL), K_39.1 (COL), K_54.1 (COL), K_73.1 (COL), U1.46 (PB9)
col10: K_10.1 (COL), K_25.1 (COL), K_40.1 (COL), K_55.1 (COL), K_66.1 (COL), K_83.1 (COL), U1.45 (PB8)
col11: K_11.1 (COL), K_26.1 (COL), K_41.1 (COL), K_56.1 (COL), K_67.1 (COL), U1.41 (PB5)
col12: K_12.1 (COL), K_27.1 (COL), K_42.1 (COL), K_57.1 (COL), K_68.1 (COL), K_82.1 (COL), U1.40 (PB4)
col13: K_13.1 (COL), K_28.1 (COL), K_43.1 (COL), K_58.1 (COL), K_69.1 (COL), K_75.1 (COL), U1.39 (PB3)
col14: K_14.1 (COL), K_29.1 (COL), K_44.1 (COL), K_59.1 (COL), K_74.1 (COL), U1.38 (PA15)
row0: D_0.1 (K), D_1.1 (K), D_2.1 (K), D_3.1 (K), D_4.1 (K), D_5.1 (K), D_6.1 (K), D_7.1 (K), D_8.1 (K), D_9.1 (K), D_10.1 (K), D_11.1 (K), D_12.1 (K), D_13.1 (K), D_14.1 (K), U1.28 (PB15/SPI2_MOSI)
row1: D_15.1 (K), D_16.1 (K), D_17.1 (K), D_18.1 (K), D_19.1 (K), D_20.1 (K), D_21.1 (K), D_22.1 (K), D_23.1 (K), D_24.1 (K), D_25.1 (K), D_26.1 (K), D_27.1 (K), D_28.1 (K), D_29.1 (K), U1.27 (PB14)
row2: D_30.1 (K), D_31.1 (K), D_32.1 (K), D_33.1 (K), D_34.1 (K), D_35.1 (K), D_36.1 (K), D_37.1 (K), D_38.1 (K), D_39.1 (K), D_40.1 (K), D_41.1 (K), D_42.1 (K), D_43.1 (K), D_44.1 (K), U1.25 (PB12)
row3: D_45.1 (K), D_46.1 (K), D_47.1 (K), D_48.1 (K), D_49.1 (K), D_50.1 (K), D_51.1 (K), D_52.1 (K), D_53.1 (K), D_54.1 (K), D_55.1 (K), D_56.1 (K), D_57.1 (K), D_58.1 (K), D_59.1 (K), U1.3 (PC14/OSC32_IN)
row4: D_60.1 (K), D_61.1 (K), D_62.1 (K), D_63.1 (K), D_64.1 (K), D_65.1 (K), D_66.1 (K), D_67.1 (K), D_68.1 (K), D_69.1 (K), D_70.1 (K), D_71.1 (K), D_72.1 (K), U1.4 (PC15/OSC32_OUT)

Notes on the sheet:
6 free pins
5 free pins
Leave R5 unpopulated as per specs for MCU
Just dont use this pin.
Leaving R1 unpopulated as per other boards
8 free pins
Internal Pulldown

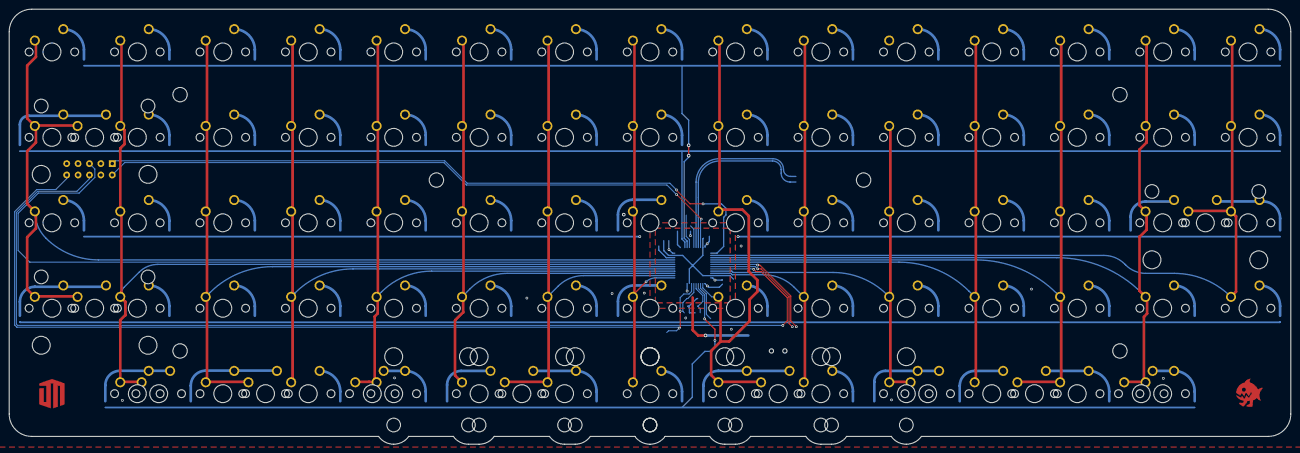
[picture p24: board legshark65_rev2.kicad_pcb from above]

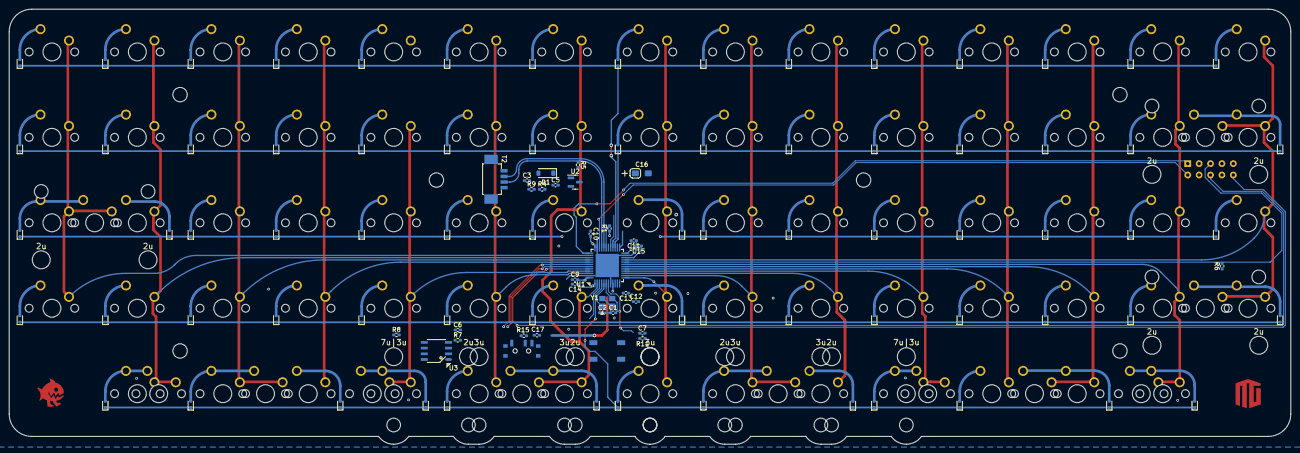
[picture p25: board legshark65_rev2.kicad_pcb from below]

Board: 2 copper layers, 285.8 x 97.0 mm, 199 parts (105 on the bottom side), 111 nets.

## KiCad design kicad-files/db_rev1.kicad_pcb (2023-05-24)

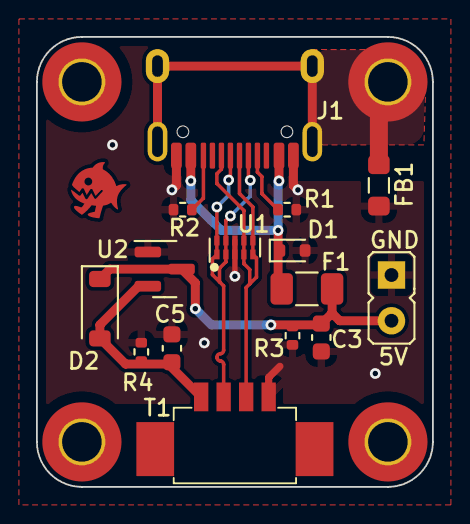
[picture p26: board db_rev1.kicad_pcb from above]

Board: 2 copper layers, 22.0 x 25.0 mm, 20 parts (0 on the bottom side), 9 nets.

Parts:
C3, C5: 1uF; C_0603_1608Metric
D1: ESD5Z5V0; D_SOD-523
D2: B5819W-SL; D_SOD-123
F1: SMD0805-050-16V; Fuse_1206_3216Metric
FB1: GZ2012D601TF; L_0805_2012Metric_Pad1.05x1.20mm_HandSolder
H1: LegSharkLogo; Legshark_Small_Mask
J1: TYPE-C-31-M-12
J2: Conn_01x02; PinHeader_1x2_P2.54mm_Vertical
MH1, MH3, MH4: Mount-M2; MountingHole_2.2mm_M2_Pad_TopOnly
MH2: Mount-M2; MountingHole_2.2mm_M2_Pad_TopBottom
R1, R2: 5.1k; R_0402_1005Metric
R3, R4: 100k; R_0402_1005Metric
T1: 53261-0471; Molex, PicoBlade, 53261, 4 Way, 1 Row, Right Angle PCB Head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
U1: TPD4E05U06DQAR; USON-10_2.5x1.0mm_P0.5mm
U2: MCP1700T-3302E/TT; SOT-23

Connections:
3V3: C5.1, D2.2 (A), R4.2, T1.1 (3V3), U2.2 (VO)
5V: C3.1, D2.1 (K), F1.2, J2.2, R3.2, U2.3 (VI)
D+: J1.A6 (D+), J1.B6 (D+), T1.3 (D-), U1.4 (D2+), U1.5 (D2-), U1.6 (NC), U1.7 (NC)
D-: J1.A7 (D-), J1.B7 (D-), T1.2 (D+), U1.1 (IO1), U1.2 (IO2), U1.9 (NC), U1.10 (NC)
GND: C3.2, C5.2, D1.2 (A2), FB1.2, J1.A1 (GND), J1.B1 (GND), J2.1, R1.2, R2.2, R3.1, R4.1, T1.4 (GND), U1.3 (GND), U1.8 (GND), U2.1 (GND)
GNDPWR: FB1.1, J1.S (SHIELD), MH2.1
unnamed: J1.A5 (CC1), R1.1
unnamed: J1.B5 (CC2), R2.1
VBUS: D1.1 (A1), F1.1, J1.A4 (VBUS), J1.B4 (VBUS)

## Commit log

2023-04-29 Init kicad files from layout
    [keyboard.kicad_pcb, keyboard.sch]
2023-04-29 Change row and col name to r and c & added acheron libs
    [keyboard.kicad_pcb, keyboard.kicad_sch]
2023-04-29 Added STM32 micro controller to schematic
    [keyboard.kicad_pcb, keyboard.kicad_sch]
2023-04-29 Added Type C connector
    [keyboard.kicad_sch]
2023-04-29 Renamed pins on STM
    [keyboard.kicad_pcb, keyboard.kicad_sch]
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2023-04-30 Swapped switches to cherry MX only & Resized board
    [keyboard.kicad_pcb, keyboard.kicad_sch]
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2023-04-30 Moved Diodes for more practical spacing
    [keyboard.kicad_pcb]
2023-04-30 Hooked up the Type C connector
    [keyboard.kicad_pcb, keyboard.kicad_sch]
2023-04-30 Connected usb GNDPWR to inductor
    [keyboard.kicad_pcb, keyboard.kicad_sch]
2023-04-30 Connected the 3V3 regulator & ESD Protection
    [keyboard.kicad_sch]
2023-04-30 Connected EEPROM to STM
    [keyboard.kicad_sch]
2023-04-30 Rename row and col to use captial
    [keyboard.kicad_sch]
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2023-04-30 Added 3V3 connections to controller
    [keyboard.kicad_pcb, keyboard.kicad_sch]
2023-05-01 Placed reset switch & eeprom footprints
    [keyboard.kicad_pcb]
2023-05-01 Connected pulldown for 3V3 on the STM
    [keyboard.kicad_pcb, keyboard.kicad_sch]
2023-05-01 Connected EEPROM and RESET to STM
    [keyboard.kicad_pcb]
2023-05-01 Moved switch for better positioning
    [keyboard.kicad_pcb]
2023-05-01 Added connector for DB
    [keyboard.kicad_pcb, keyboard.kicad_sch]
2023-05-02 Added the cable header for DB to MB
    [keyboard.kicad_pcb, keyboard.kicad_sch]
2023-05-02 Added fill area for MB
    [keyboard.kicad_pcb]
2023-05-02 Connected all 3V3 to STM
    [keyboard.kicad_pcb, keyboard.kicad_sch]
2023-05-02 Started piecing together daughter board
    [keyboard.kicad_pcb]
2023-05-02 Finished ic placement for daughter board
    [keyboard.kicad_pcb]
2023-05-02 Straightened up the daughter board
    [keyboard.kicad_pcb]
2023-05-02 Completed wiring and zoning daughter board
    [keyboard.kicad_pcb]
2023-05-02 Added legshark logo to DB
    [keyboard.kicad_pcb]
2023-05-02 Rotated the molex header on the main board
    [keyboard.kicad_pcb]
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2023-05-07 Moved the reset swtich
    [keyboard.kicad_pcb]
2023-05-07 Moved some devices further away from stab mount
    [keyboard.kicad_pcb]
2023-05-07 Added cut-outs around arrow keys and fixed boarder size
    [keyboard.kicad_pcb]
2023-05-07 Started re-routing the columns to be a lot more efficient
    [keyboard.kicad_pcb]
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2023-05-07 Corrected sizing for the arrow key cutouts
    [keyboard.kicad_pcb]
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2023-05-07 Fixed unconnectd GND issues
    [keyboard.kicad_pcb]
2023-05-07 Fixed C0 not being curvy
    [keyboard.kicad_pcb]
2023-05-07 Moved some things around a little and added teardrops
    [keyboard.kicad_pcb, keyboard.kicad_sch]
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2023-05-09 Fix distanc
    [keyboard.kicad_pcb]
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2023-05-10 Swapped reset switch to less complicated SPDT switch
    [keyboard.kicad_pcb, keyboard.kicad_sch]
2023-05-10 Re connected the new reset functionality
    [keyboard.kicad_pcb, keyboard.kicad_sch]
2023-05-10 Moved resister further away from a MCU pin
    [keyboard.kicad_pcb]
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2023-05-10 Fixed some 3v3 routing to be cleaner
    [keyboard.kicad_pcb]
2023-05-10 Routed the Columns along the bottom and connected to MCU
    [keyboard.kicad_pcb, keyboard.kicad_sch]
2023-05-10 Rejiggered row and col wires to avoid holes with new clearence settings
    [keyboard.kicad_pcb]
2023-05-10 Added no ground pour to USB data wires to aesthetics
    [keyboard.kicad_pcb]
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2023-05-10 Swapped back to thermal reliefs beacuse I read the internet
    [keyboard.kicad_pcb, keyboard.kicad_sch]
2023-05-11 Added Serial Wire Debug header for CLK and DIO pins
    [keyboard.kicad_pcb, keyboard.kicad_sch]
2023-05-11 Updated molex header to be more accurate with better footprint
    [keyboard.kicad_pcb]
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2023-05-14 Updated to version 2 of the board layout
    [keyboard.kicad_pcb]
2023-05-15 Added new kicad project for version 2 layout and coppied the MCU schematic
    [keyboard.sch, legshark65.kicad_pcb, legshark65.kicad_sch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]
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2023-05-16 Created power pour on F and more wiring completion
    [legshark65.kicad_pcb]
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2023-05-17 Connected all of the wires of the new board
    [legshark65.kicad_pcb, legshark65.kicad_sch]
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2023-05-21 Fixed up the daughter board
    [daughter_board.kicad_pcb, daughter_board.kicad_sch, legshark65.kicad_pcb]
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2023-05-21 Fixed the boards edge cuts
    [daughter_board.kicad_pcb]
2023-05-22 Fixing up the schematic's of daughter and mother boards
    [daughter_board.kicad_pcb, daughter_board.kicad_sch, legshark65.kicad_pcb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]
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2023-05-22 More minor clearance changes
    [legshark65.kicad_pcb, legshark65.kicad_sch]
2023-05-22 Added some front graphics to the motherboard pcb
    [legshark65.kicad_pcb, legshark65.kicad_sch]
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2023-05-24 Finished add BOM to motherboard & fixing some small parts
    [legshark65.kicad_pcb, legshark65.kicad_sch]
2023-05-24 Added header for 5V on daughter board and updated BOM a little
    [daughter_board.kicad_pcb, daughter_board.kicad_sch]
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2023-05-25 Lots of small routing and quality changes to the motherboard
    [legshark65.kicad_pcb]
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2023-06-04 Made some very slight changes as per processing
    [legshark65.kicad_pcb, legshark65.kicad_sch]
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2023-07-02 Moved the branding and JTAG to be positioned more between the switches
    [legshark65.kicad_pcb]
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2023-07-23 Made diodes small and fixed some connections
    [keyboard.kicad_pcb, keyboard.kicad_sch]
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2023-07-24 Added the 5V to 3V3 stepdown schematic from db to the mb
    [legshark65_rev2.kicad_pcb, legshark65_rev2.kicad_sch]
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2023-07-25 Added 3U stabs to the 7U footprint for even more layout support
    [legshark65_rev2.kicad_pcb, legshark65_rev2.kicad_sch]
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2023-07-26 Starting to come up with ways mount the board
    [legshark65_rev2.kicad_pcb]
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2023-07-26 Started adding all of the components onto the board
    [legshark65_rev2.kicad_pcb, legshark65_rev2.kicad_sch]
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2023-07-27 Moved the JTAG and routed NRST and BOOT0 to it
    [legshark65_rev2.kicad_pcb]
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2023-07-27 Made the pours correct distance
    [legshark65_rev2.kicad_pcb]
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2023-07-30 Lots of small changes all over the board changes most of the wires down to 0.4mm instead of 0.6
    [legshark65_rev2.kicad_sch]
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2023-07-30 fixed board
2023-07-31 Made the mounting holes sold connection to gnd
    [legshark65_rev2.kicad_sch]
2023-07-31 Making the tracks have a more consistant width
    [legshark65_rev2.kicad_sch]
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2023-08-01 Added plate with correct stab rotation
    [legshark65_rev2_plate.dxf]
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2023-08-09 Added extra 1.5 and cut out the corners
    [legshark65_rev2.kicad_sch]
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2023-08-20 Added better less broken silkscreen graphic
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2023-11-01 Added bigger cutouts and deciding what to do with stab mounts
    [legshark65_rev2.kicad_sch]
2023-11-03 Changes stab hole size to be a bit tighter
    [legshark65_rev2.kicad_sch]
2023-11-03 Went all out and added more 2u options because im insane
    [legshark65_rev2.kicad_sch]
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2024-01-05 Move JST over to give room for connector
    [legshark65_rev2.kicad_sch]
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
